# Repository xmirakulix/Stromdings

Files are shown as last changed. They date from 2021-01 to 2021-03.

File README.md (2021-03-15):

# Stromdings - 16-port smart power meter

Stromdings uses an ATMEGA328 microcontroller and four MCP3304 analog-digital converters to measure the power on up to 16 circuits using current transformers.
Measurements are transmitted via WiFi to a home assistant server using mqtt.

Features:
- Measure up to 16 ports 
- Up to 16A (3.6kW @ 230V) per port
- Non-invasive installation using 'clip on' current transformer clamps
- +/- 2 Watt accuracy
- Transmit measurements via WiFi using MQTT

## Software

Stromdings is an Arduino project, developed in VSCode using the [PlatrormIO extension](https://marketplace.visualstudio.com/items?itemName=platformio.platformio-ide). It runs on an 16MHz ATMega328P microcontroller.

Requirements to the microcontroller:
- Analog port with hardware pinchange interrupt
- Two serial ports or support for software serial interface
- Serial peripheral interface (SPI)
- i2c bus

Used third party libraries:
- Software serial: [AltSoftSerial](https://github.com/xmirakulix/AltSoftSerial) (forked)
- WiFi (ESP8266): [WiFiEspAT](https://github.com/xmirakulix/WiFiEspAT) (forked)
- i2c LCD (16x2): [hd44780](https://github.com/duinoWitchery/hd44780)
- MQTT: [pubsubclient](https://github.com/xmirakulix/pubsubclient) (forked)

## Hardware

- ATMega328P microcontroller
- MCP3304 analog-digital converters
- [YHDC SCT-013](http://en.yhdc.com/product/SCT013-401.html) 100A current transformers (1:2000 turns)
- 220 Ohm shunt resistors for measurements up to 16A (3.6kW @ 230V) per port
- ESP-01 WiFi module using ESP8266 chip
- LCD Display with 16x2 characters via i2c
- Rotary encoder to select displayed info on the LCD

## Schematics / PCB design

Schematics and PCB was designed using the [EasyEDA](https://easyeda.com/) online editor. Schematics, PCB Design and final Gerber-Files are available in the 'doc' folder.

Schematics: https://github.com/xmirakulix/Stromdings/raw/master/doc/Schematics.pdf

PCB: 

PCB PCB design

## Ideas for the future

- PCB: D1 orientation wrong
- PCB: add reset button
- PCB: Power cycle possibility for ESP-01
- PCB: Optimize 2.5V ref voltage track routing
- PCB: Check debounce cap necessity for rotary

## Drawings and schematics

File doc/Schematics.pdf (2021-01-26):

## GND

+5V

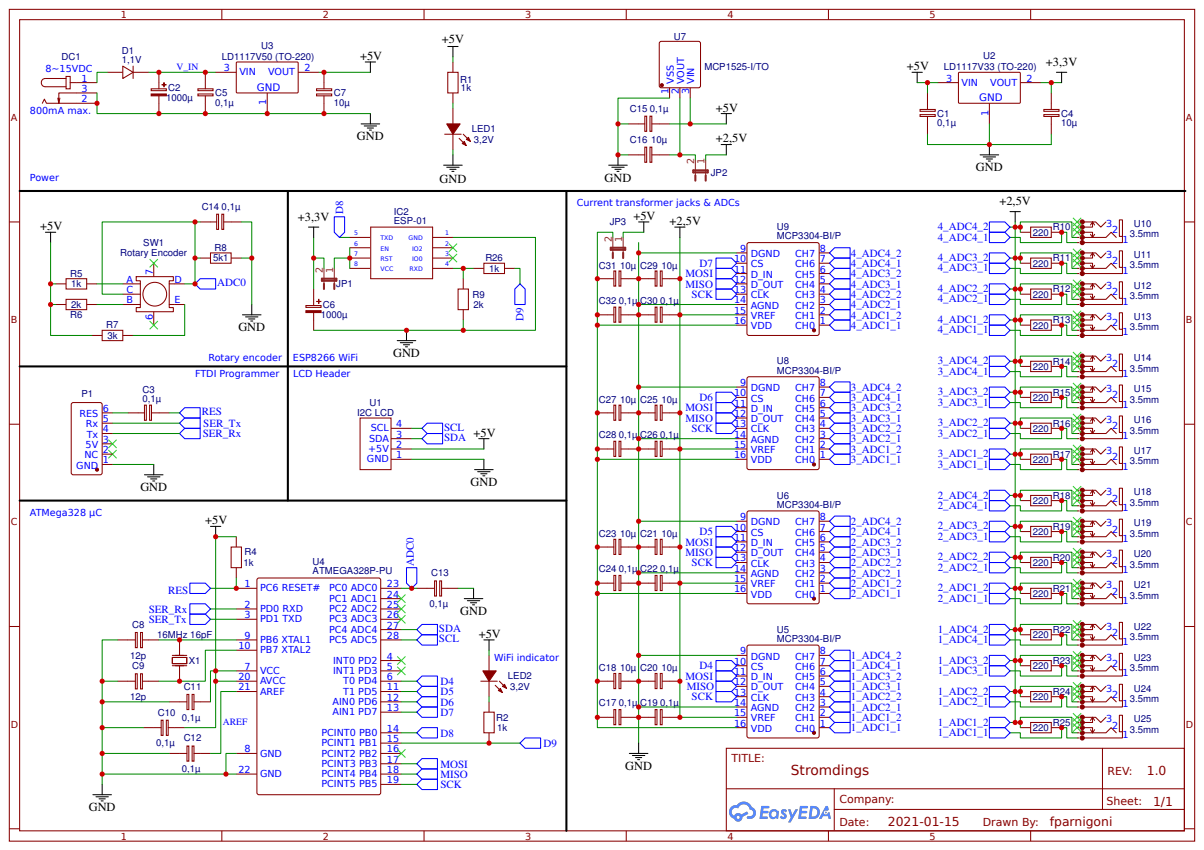
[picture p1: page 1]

Current transformer jacks & ADCs

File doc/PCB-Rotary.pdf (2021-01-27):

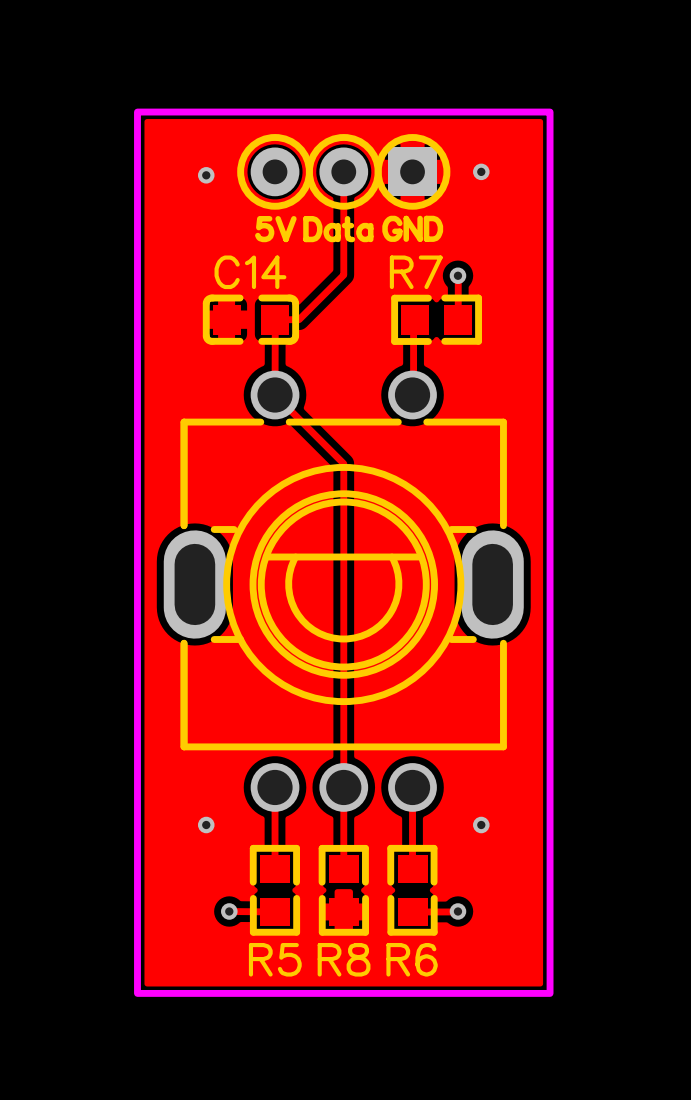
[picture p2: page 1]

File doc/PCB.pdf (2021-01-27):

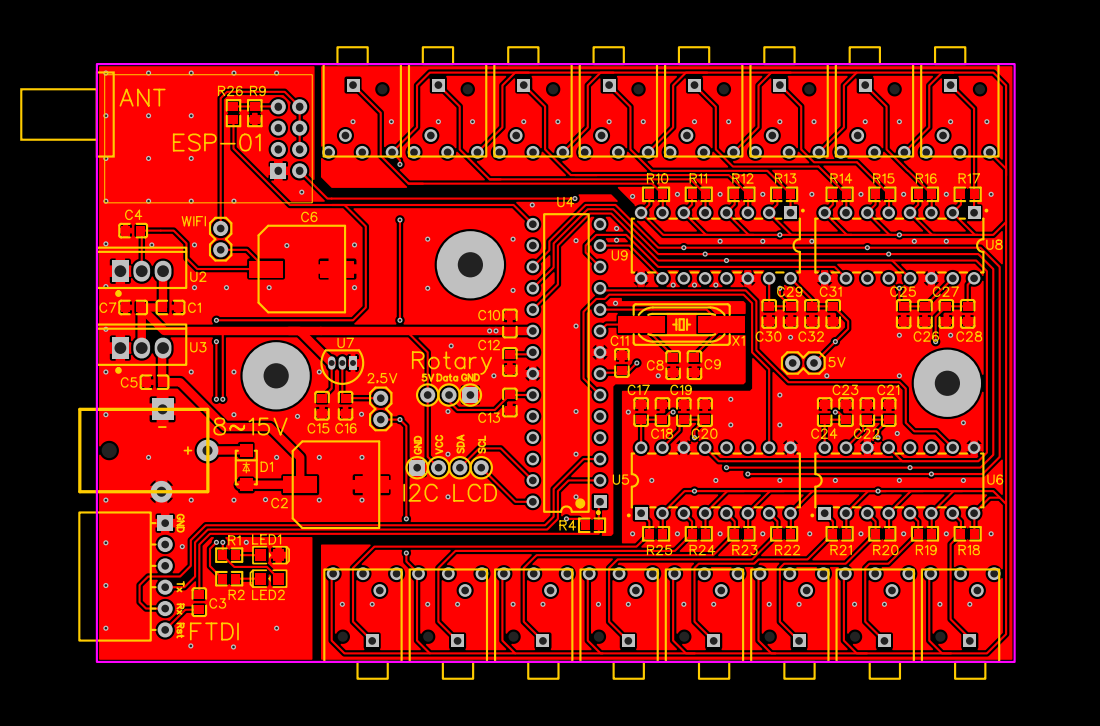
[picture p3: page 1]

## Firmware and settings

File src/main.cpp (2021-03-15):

#include <Arduino.h>
#include <Wireless.h>
#include <Lcd.h>
#include <Power.h>
#include <Rotary.h>

// ################# Main stuff #################

void setup()
{
  // setup Serial for debugging
  Serial.begin(9600);
  while (!Serial)
    delay(10);

  // setup LCD
  setupLcd();

  // setup and connect WiFi
  setupWifi();
  connectWiFi();

  setupMqtt();

  // setup power measurement
  setupPower();

  // setup the rotary ecoder
  setupRotary();
}

void loop()
{
  handleWiFi();
  handleMqtt();
  handlePower();
  handleLcd();
}

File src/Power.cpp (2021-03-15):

#include <Power.h>
#include <Wireless.h>
#include <SPI.h>

// #define DEBUG  // toggle Debug Output

#ifdef DEBUG
unsigned long m_PowerHandlerDuration = 0; // store the duation of last handler run
#endif

// ######## Power measurement
const uint8_t m_CsPins[] = {4, 5, 6, 7};                     // list of ADC Chip-Select pins
const uint8_t m_AdcCnt = sizeof(m_CsPins) / sizeof(uint8_t); // number of ADCs
const uint8_t m_NumPorts = m_AdcCnt * 4;                     // number of available ports
uint16_t m_LastMeasurements[m_NumPorts];                     // last measurement per port
unsigned long m_LastMeasureTime = 0;                         // time of last measurement
uint8_t m_curMeasurePort = 0;                                // last measured Pin

// const int m_PsuCalibration = 228.20;               // calibration factor for used 9VAC PSU

// ################# POWER stuff #################

void handlePower()
{
#ifdef DEBUG
  m_PowerHandlerDuration = millis();
#endif

  unsigned int measureInterval = 1 * 1000; // in ms
  // do power measurements
  if ((millis() - m_LastMeasureTime) > measureInterval)
  {
    m_LastMeasureTime = millis();

    // 0x0 (00|00) to 0xF (11|11) -> 4x chip | 4x pin
    int csPin = m_curMeasurePort >> 2; // extraxt chip
    int adcPin = m_curMeasurePort & 3; // extract pin

#ifdef DEBUG
    Serial.print(F("Measuring: Port:"));
    Serial.print(m_curMeasurePort);
    Serial.print(F(", Chip: "));
    Serial.print(m_CsPins[csPin]);
    Serial.print(F(", Pin: "));
    Serial.println(adcPin);
#endif

    int measureDuration = 20 * 1000; // 20k µs, 50Hz = 20ms per wave
    m_LastMeasurements[m_curMeasurePort] = getAdcPower(m_CsPins[csPin], adcPin, measureDuration, 220, 2000, 230);

#ifdef DEBUG
    Serial.print(F("W["));
    Serial.print(m_curMeasurePort);
    Serial.print(F("]: "));
    Serial.print(m_LastMeasurements[m_curMeasurePort]);
    Serial.println();
#endif

    sendMeasurement(m_curMeasurePort);
    m_curMeasurePort++;
    if (m_curMeasurePort == m_NumPorts)
      m_curMeasurePort = 0;
  }

#ifdef DEBUG
  Serial.print(F("Power handler took: "));
  Serial.print(millis() - m_PowerHandlerDuration);
  Serial.println(F("ms"));
#endif
}

/*
 * setup the SPI bus and the CS pins
 *	csPins: array containing the cs pin numbers on the arduino
 *
 * Return: none
 */
void setupPower()
{
  SPI.begin(); // init the SPI bus
  for (int i = 0; i < m_AdcCnt; i++)
  {
    pinMode(m_CsPins[i], OUTPUT);    // set CS pin to output
    digitalWrite(m_CsPins[i], HIGH); // pull CS pin high to disable the ADCs
  }
  delay(1);
}

/*
 * Get Reading from ADC and convert to Voltage
 *	csPin: Arduino chipselect pin for this ADC
 *	adcPin: which input pin to use on ADC (MCP3304: 0,2,4,6)
 *	measureDuration: measure interval in usec
 *	corrector: correction value specific to used AC/AC power supply
 *
 * Return: Voltage in V
 */
float getAdcVoltage(int csPin, int adcPin, unsigned long measureDuration, float calibration)
{
  unsigned long lsbValue = 610351; // 1 bit in nV (=5V/2^13)
  unsigned long voltage = 0;
  float primVoltage = 0;

  int adcVal = readAdcRms(csPin, adcPin, measureDuration);

  // strange order to maximize accuracy (max_val = 2^32)
  voltage = adcVal * lsbValue;         // reading in nV
  voltage /= 1000000;                  // conv to mV
  primVoltage = voltage * calibration; // upscale to primary
  primVoltage /= 1000;                 // conv to V

#ifdef DEBUG
  Serial.print(F("getAdc: "));
  Serial.print(adcVal);
  Serial.print(F(" V: "));
  Serial.print(primVoltage);
  Serial.println();
#endif

  return primVoltage;
}

/*
 * Get Reading from ADC and convert to Power (W)
 *	csPin: Arduino chipselect pin for this ADC
 *	adcPin: which input pin to use on ADC (MCP3304: 0,2,4,6)
 *	measureDuration: measure interval in usec
 *	shuntOhms: size of measure shunt in Ohm
 *	turns: count of turns in current transformer (e.g. 2000 for 1:2000)
 *	voltage: voltage to use for power calculation
 *
 * Return: Power in W
 */
int getAdcPower(int csPin, int adcPin, unsigned long measureDuration, int shuntOhms, int turns, int voltage)
{
  unsigned long power = 0;
  unsigned long lsbValue = 610351; // 1 bit in nV (=5V/2^13)

  if (shuntOhms == 0)
  {
#ifdef DEBUG
    Serial.println(F("##### ERROR getAdcPower(): shuntOhms=0, div/0!"));
#endif
    return 0;
  }

  int adcVal = readAdcRms(csPin, adcPin, measureDuration);

  // strange order to maximize accuracy (max_val = 2^32)
  power = (adcVal * lsbValue); // convert to nV;	46 * 610.351 = 28.076.146
  power /= shuntOhms;          // conv to sek A	28.076.146 / 220 = 127.618,8454
  power /= 1000;               //					127.618 / 1000 = 127
  power *= turns;              // conv to prim A	127 * 2000 = 254.000
  power /= 1000;               //					254.000 / 1000 = 254
  power *= voltage;            // conv to W(rms)	254 * 229 = 58.166
  power /= 1000;               //					58.166 / 1000 = 58

#ifdef DEBUG
  Serial.print(F("getAdcPower() Res: "));
  Serial.print(adcVal);
  Serial.print(F(" Power: "));
  Serial.print(power);
  Serial.println();
#endif

  return int(power); // Power in W
}

/*
 * Get Reading from ADC
 *	csPin: Arduino chipselect pin for this ADC
 *	adcPin: which input pin to use on ADC (MCP3304: 0,2,4,6)
 *
 * Return: 13-bit value from ADC
 */
int readAdc(int csPin, int adcPin)
{
  int adcValue = 0;      // nimmt den Messwert vom ADC auf
  byte hi, lo, sign = 0; // results of ADC reads

  adcPin *= 2;                        // 4 adcPins are 0, 2, 4, 6
  digitalWrite(csPin, LOW);           // turn on chipselect
  SPI.transfer(0x08 | (adcPin >> 1)); // send: 4x null, startbit, DIFF = 0, 2 Channelbits (D2, D1); return: uninteressant
  hi = SPI.transfer(adcPin << 7);     // send: lowest Channelbit (D0), rest dont care; return: 2 undef, nullbit, Signbit, 4 highest databits
  lo = SPI.transfer(0x00);            // send: dont care; return: 8 lowest databits
  digitalWrite(csPin, HIGH);          // turn off chipselect
  sign = hi & 0x10;                   // extract Sign Bit for DIFF
  adcValue = ((hi & 0x0F) << 8) + lo; // combine the 2 return Values

  if (sign)
    adcValue -= 4096; // if signbit is set, range is 0xFFF = -1 to 0x000 = -4096

  return adcValue;
}
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

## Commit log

2021-01-07 networking and power initially complete
2021-01-08 local libraries, rotary encoder, new SoftSerial
2021-01-10 rotary levels for external power supply
2021-01-23 Schema created
    [Schematics_Altium.schdoc]
2021-01-26 PCB created
    [Schematics_Altium.schdoc]
2021-01-27 Rotary PCB added
2021-01-30 PCB added as .svg
2021-01-30 remove voltage measurement
